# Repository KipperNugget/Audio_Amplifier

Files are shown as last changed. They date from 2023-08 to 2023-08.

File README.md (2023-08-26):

# ENGR 301 (Microelectronics Lab): Audio Amplifier

The goal of this project was to design, source components, and assemble an audio amplifier

EAGLE was utilized to design the pcb
LTspice was utilized for simulation

### Schematic




### Board
Please excuse the disgusting finish; attempted cleaning with isopropyl alcohol, but the flux continued to stain the board.




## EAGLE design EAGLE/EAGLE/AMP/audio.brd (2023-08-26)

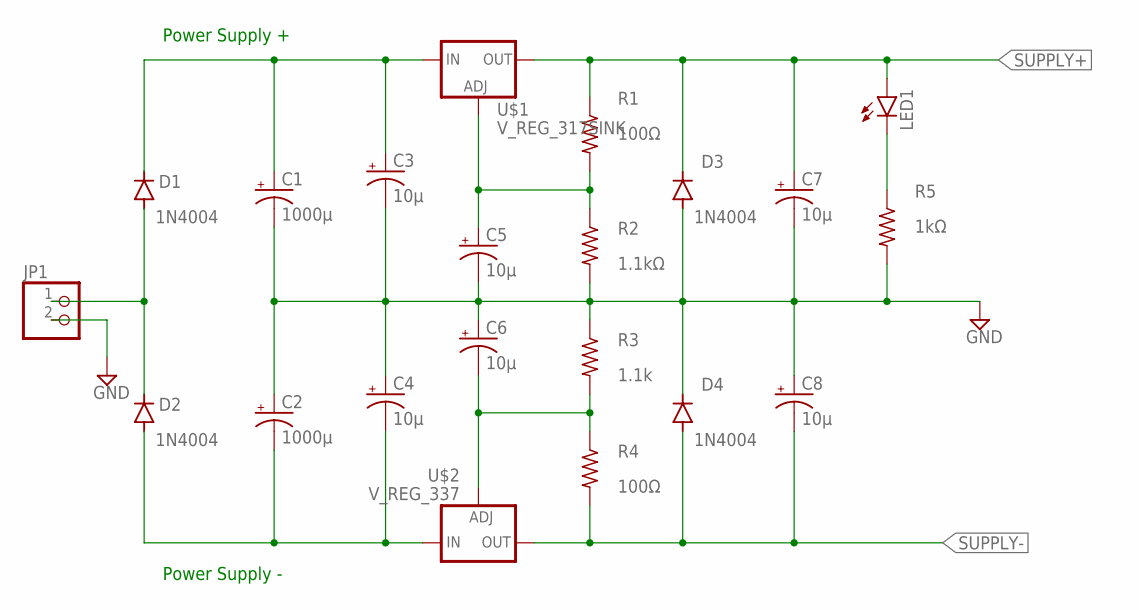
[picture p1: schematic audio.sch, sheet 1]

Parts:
C1, C2: 1000μ; E3,5-10
C3, C4, C5, C6, C7, C8: 10μ; E1,8-4
D1, D2, D3, D4: 1N4004; DO41-10
JP1: PINHD-1X2; 1X02
LED1: LED3MM
R1, R4: 100Ω; 0204/7
R2: 1.1kΩ; 0204/7
R3: 1.1k; 0204/7
R5: 1kΩ; 0204/7
U$1: V_REG_317SINK; TO220-ADJ
U$2: V_REG_337; TO220-ADJ-NEG

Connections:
GND: C1.-, C2.+, C3.-, C4.+, C5.-, C6.+, C7.-, C8.+, D3.A, D4.C, JP1.2, R2.2, R3.1, R5.2; also elsewhere on the board
unnamed: C1.+, C3.+, D1.C, U$1.IN
unnamed: C2.-, C4.-, D2.A, U$2.IN
unnamed: D1.A, D2.C, JP1.1
unnamed: C5.+, R1.2, R2.1, U$1.ADJ
unnamed: C6.-, R3.2, R4.1, U$2.ADJ
unnamed: LED1.K (C), R5.1
SUPPLY+: C7.+, D3.C, LED1.A, R1.1, U$1.OUT; also elsewhere on the board
SUPPLY-: C8.-, D4.A, R4.2, U$2.OUT; also elsewhere on the board

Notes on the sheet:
Power Supply -
Power Supply +

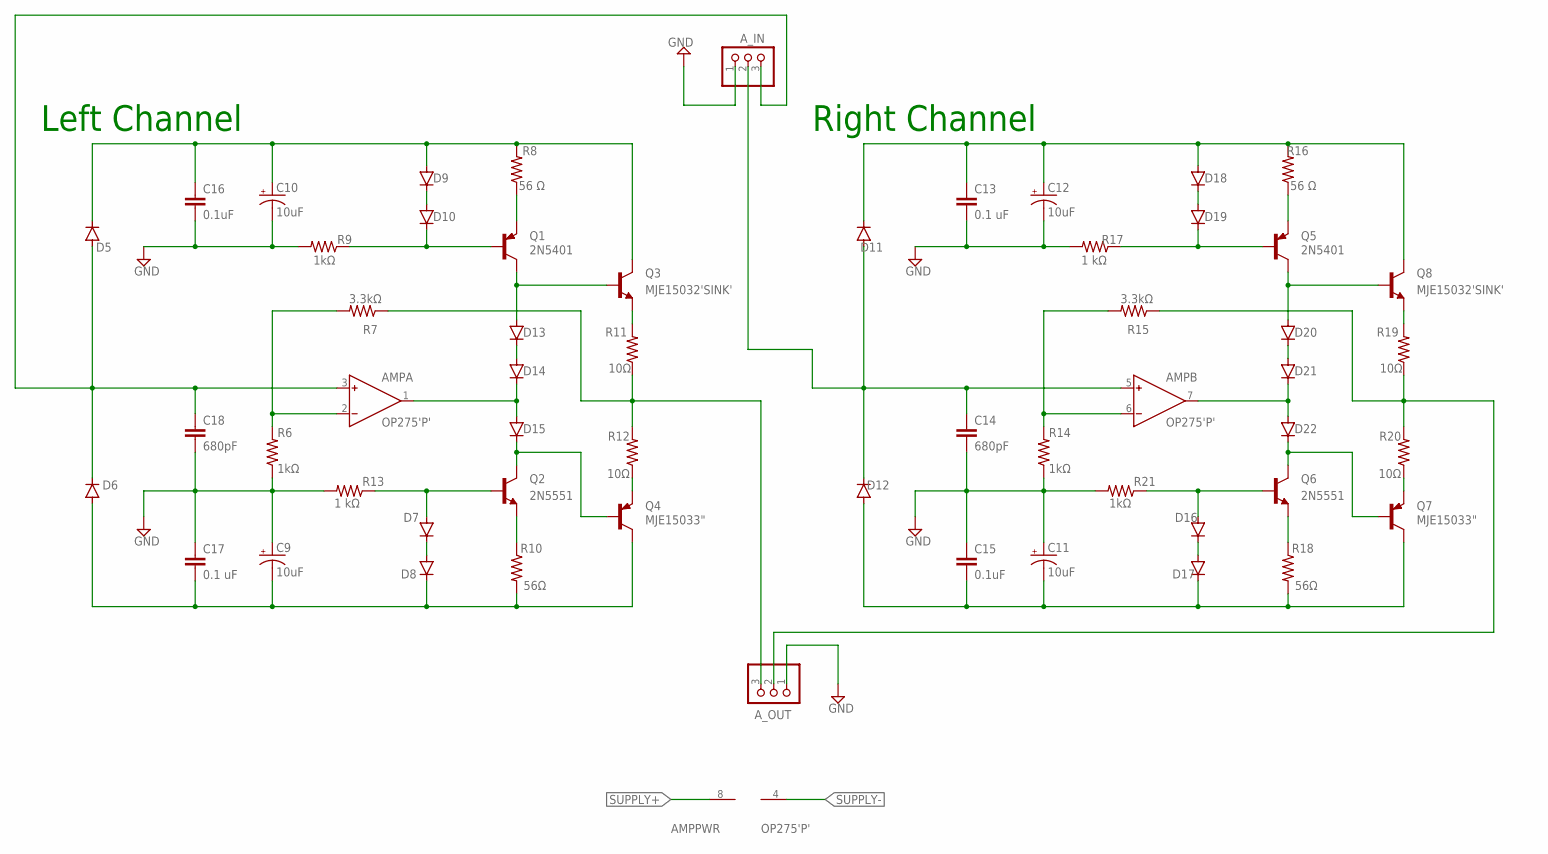
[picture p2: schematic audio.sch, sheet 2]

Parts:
AMP: OP275'P'; DIL08
A_IN: PINHD-1X3; 1X03
A_OUT: PINHD-1X3; 1X03
C9, C10, C11, C12: 10uF; E1,8-4
C13, C17: 0.1 uF; C2.5-3
C14, C18: 680pF; C2.5-3
C15, C16: 0.1uF; C2.5-3
D5, D6, D7, D8, D9, D10, D11, D12, D13, D14, D15, D16, D17, D18, D19, D20, D21, D22: 1N4148DO35-7; DO35-7
Q1, Q5: 2N5401
Q2, Q6: 2N5551
Q3, Q8: MJE15032'SINK'; TO220V-SINK
Q4, Q7: MJE15033"; TO220V-SINK
R6, R9, R14, R21: 1kΩ; 0204/7
R7, R15: 3.3kΩ; 0204/7
R8, R16: 56 Ω; 0204/7
R10, R18: 56Ω; 0204/7
R11, R12, R19, R20: 10Ω; 0204/7
R13, R17: 1 kΩ; 0204/7

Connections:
GND: A_IN.1, A_OUT.1, C9.+, C10.-, C11.+, C12.-, C13.2, C14.2, C15.1, C16.2, C17.1, C18.2, R6.1, R9.2, R13.2, R14.1, R17.2, R21.2; also elsewhere on the board
unnamed: AMP.3 (IN+), A_IN.3, C18.1, D5.A, D6.C
unnamed: C9.-, C17.2, D6.A, D8.C, Q4.2 (C), R10.2
unnamed: D7.C, D8.A
unnamed: C10.+, C16.1, D5.C, D9.A, Q3.2 (C), R8.2
unnamed: D9.C, D10.A
unnamed: AMP.2 (IN-), R6.2, R7.2
unnamed: Q1.E, R8.1
unnamed: D13.C, D14.A
unnamed: D13.A, Q1.C, Q3.1 (B)
unnamed: AMP.1 (OUT), D14.C, D15.A
unnamed: D15.C, Q2.C, Q4.1 (B)
unnamed: Q2.E, R10.1
unnamed: D10.C, Q1.B, R9.1
unnamed: Q3.3 (E), R11.2
unnamed: Q4.3 (E), R12.1
unnamed: D7.A, Q2.B, R13.1
unnamed: A_OUT.3, R7.1, R11.1, R12.2
unnamed: AMP.5 (IN+), A_IN.2, C14.1, D11.A, D12.C
unnamed: C11.-, C15.2, D12.A, D17.C, Q7.2 (C), R18.2
unnamed: D16.C, D17.A
unnamed: C12.+, C13.1, D11.C, D18.A, Q8.2 (C), R16.2
unnamed: D18.C, D19.A
unnamed: AMP.6 (IN-), R14.2, R15.2
unnamed: Q5.E, R16.1
unnamed: D20.C, D21.A
unnamed: D20.A, Q5.C, Q8.1 (B)
unnamed: AMP.7 (OUT), D21.C, D22.A
unnamed: D22.C, Q6.C, Q7.1 (B)
unnamed: D19.C, Q5.B, R17.1
unnamed: Q6.E, R18.1
unnamed: Q8.3 (E), R19.2
unnamed: Q7.3 (E), R20.1
unnamed: D16.A, Q6.B, R21.1
unnamed: A_OUT.2, R15.1, R19.1, R20.2
SUPPLY+: AMP.8 (V+); also elsewhere on the board
SUPPLY-: AMP.4 (V-); also elsewhere on the board

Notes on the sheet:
Left Channel
Right Channel

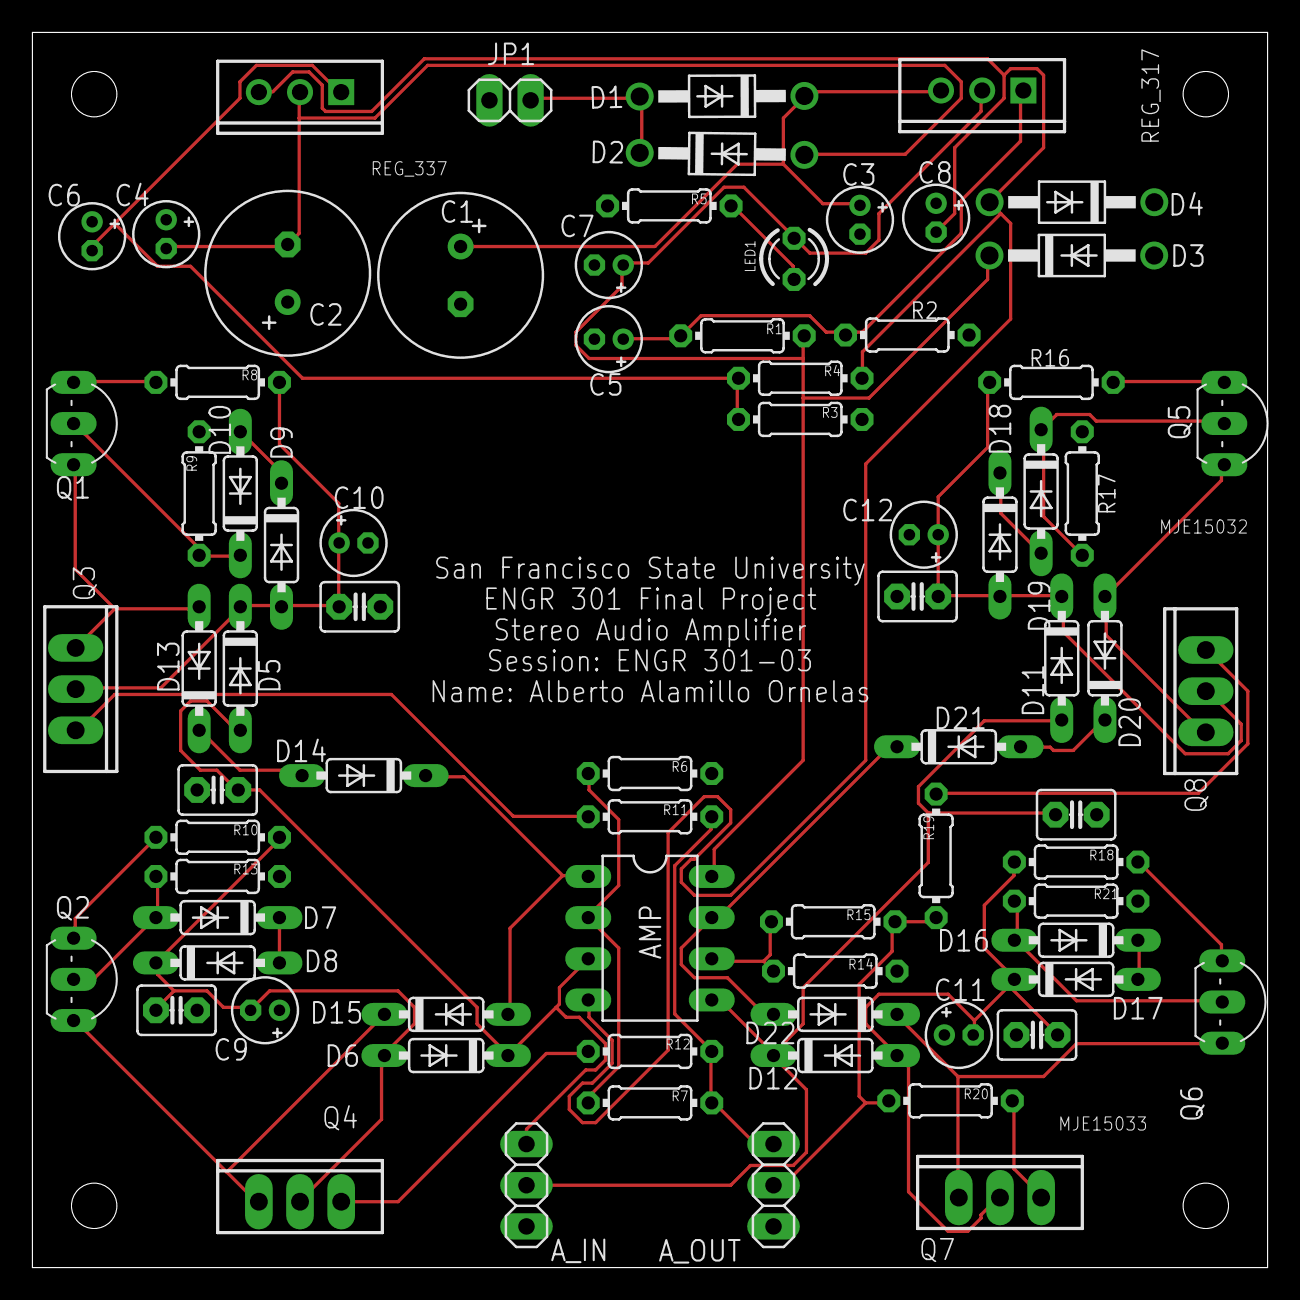
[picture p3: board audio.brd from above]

Board: 2 copper layers, 76.2 x 76.2 mm, 76 parts (0 on the bottom side), 43 nets.
